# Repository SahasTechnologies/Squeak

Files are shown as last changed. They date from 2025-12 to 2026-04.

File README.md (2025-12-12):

## Squeak Mouse

Here is my custom designed mouse! It's my first time on Onshape, so I don't know how well this will turn out but a good chance to learn about how to use onshape. The finished product is [here](https://github.com/SahasTechnologies/Squeak/blob/main/Squeak%20All%20Parts%20(DO%20NOT%20PRINT).step) and the image is below:

+¬¦˜+¦+¦¦+¦s

The other 3 files can be printed to put together to get an assembled mouse!

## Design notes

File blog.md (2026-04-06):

<!--
  This journal is auto generated by Hack Club Blueprint.
-->

# 12/13/2025 8 AM - Squeak  

_Time spent: 0.5h_  

I am following this guide:


It says no journal required so I won't journal on the mouse CAD design and development. I'll just journal the finished mouse  

# 12/13/2025 9 AM - Finished!  

_Time spent: 4.0h_  

My CAD: [Squeak](https://cad.onshape.com/documents/1791d452b1ce2d56df0d7c44/w/8ed75c21a1f838e67c8c7ae7/e/896395b3e92be339e637faea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)

\

I'll ask someone in Printing Legion to print it, here are the 3MF Files

[+¬¦˜+¦+¦¦+¦s](/user-attachments/blobs/proxy/eyJfcmFpbHMiOnsiZGF0YSI6MjMyMTAsInB1ciI6ImJsb2JfaWQifX0=--c7a4f6c06d3aa04bb595d4f705606054159b0e09/%2B%C2%AC%C2%A6%CB%9C%2B%C2%A6%2B%C2%A6%C2%A6%2B%C2%A6s.3mf)
[+¬¦˜+¦+¦¦+¦s - battery tab](/user-attachments/blobs/proxy/eyJfcmFpbHMiOnsiZGF0YSI6MjMyMTEsInB1ciI6ImJsb2JfaWQifX0=--efa1e4063500dd317ee7b0db9eb5cb296b28a180/%2B%C2%AC%C2%A6%CB%9C%2B%C2%A6%2B%C2%A6%C2%A6%2B%C2%A6s%20-%20battery%20tab.3mf)
[+¬¦˜+¦+¦¦+¦s - base](/user-attachments/blobs/proxy/eyJfcmFpbHMiOnsiZGF0YSI6MjMyMTIsInB1ciI6ImJsb2JfaWQifX0=--f1f21aa12148745eb043641fe057322c68a11a4b/%2B%C2%AC%C2%A6%CB%9C%2B%C2%A6%2B%C2%A6%C2%A6%2B%C2%A6s%20-%20base.3mf)

# 12/14/2025 - BOM  

_Time spent: 1.0h_  

[My BOM](https://github.com/SahasTechnologies/Squeak/blob/main/bom.csv)

| Item | Price in AUD | Price in USD | Shipping (USD) | Total Cost (USD) |
|---|---|---|---|---|
| Bambu Lab Mouse Kit | $16 | ~$11 | ~$6 | $17 |
| 3D prints | $0 | $0 | $12 (max) | $12 |
| | | | | $29



# 1/22/2026 8:19 AM - Components arrived  

_Time spent: 0.5h_  

🎉🎉🎉
Now that the printlegion stuff arrived i can actually stary making. First look though, many of the parts were printed separately instead of together, so super gluing all of this together won't be that easy...



# 1/22/2026 8:24 AM - Assembled all components  

_Time spent: 1.5h_  

mouse
[Video of the mouse working](/user-attachments/blobs/proxy/eyJfcmFpbHMiOnsiZGF0YSI6ODc4MTYsInB1ciI6ImJsb2JfaWQifX0=--4eaad5631bd95a56bf42be9cb9b51019d38cb931/20260121_195300.mp4)

# 1/22/2026 8:28 AM - Noooooooo  

_Time spent: 0.5h_  

So, as i was saying earlier in need to superglue the parts on, and when I tried to  assemble of the 3d parts... it just broke 🙁

It's not that bad since im going to super glue it anyway and even if i dont it doesnt cause any harm to my actual project, but either way it's sad that I already broke a part



Before assembling though I had spent some time putting the parts together because there are many small parts that should have been printed eith the actual case (e.g the protrusions on the inside of the mouse case that actually click the button)

Here is how the mouse should look like when im done


# 1/25/2026 3:11 PM - Superglued first part on  

_Time spent: 2.5h_  

This took a bit of time to setup and do. Before I start, it's important to understand that in my CAD design, this was all one file, but the slicer had made them two separate objects entirely. Therefore, there is no clearance space to wedge the parts in together sadly.

I spent a lot of time trying to get the parts to actually fit in 😶



So, after trying a lot to wedge, I had to resort to cutting a bit of filament off (and hoping the screw hole still works for later).


So, now after a long time it finally decided to fit on, which is a relief. But, it didnt fit perfectly and kept springing back no matter how hard i tried

So i had to superglue these parts to each other so that they can actually fit  

# 1/25/2026 3:19 PM - Assembled rest of the mouse  

_Time spent: 1.0h_  



The mouse is fully assembled now and it is working so yeah, here is a video of jt working[20260125_151815](/user-attachments/blobs/proxy/eyJfcmFpbHMiOnsiZGF0YSI6OTA2MTYsInB1ciI6ImJsb2JfaWQifX0=--8417cb071001bc2bd6b273fe5f60a4531131c02e/20260125_151815.mp4)

# 1/26/2026 - Social media  

_Time spent: 1.0h_  

social media is sadly banned in australia for under 16s
also jay said i can uplaod to cdn 
[see here](https://hackclub.slack.com/archives/C09CMJV6V6K/p1766012356714549?thread_ts=1766006526.978849&cid=C09CMJV6V6K)
anyway so yeah here is my mouse



if you specifically need it in #cdn then here is the video in cdn
oh wait cdn doesnt work thats sad
here is the link to the file on slack at least
https://hackclub.enterprise.slack.com/files/U09QBEKG4S0/F0AAZ6FHDNG/20260125_151815.mp4

I got this error for #cdn:
https://hackclub.slack.com/archives/C016DEDUL87/p1769384952272139?thread_ts=1769384947.905419&cid=C016DEDUL87
thanks, i'm gonna sell these to adfly![10:49 AM]orpheus trips and your files slip out of her hands and into an inconveniently placed sewer grate.[10:49 AM]Something went wrong: RuntimeError: cdn returned error 500: {"error":"Internal server error"}      
// stack trace:
/app/app/interactions/cdn.rb:29:in `upload_to_cdn'
/app/app/interactions/cdn.rb:47:in `block in call'
// nora, please go find the full trace
// code available at https://github.com/hackclub/orpheus-bot
error ID: 34df5310-1e1d-4d2a-8b78-ae203bc0a99f  

# 07/4/2026 - Improvements for next time

_Time spent: 0.1h_  

This is very sad...
I got the mouse to 'work', but while supergluing everything, some liquid fell inside the right button :(
tempFileForShare_20260407-073727

So now, the left click works perfectly, but the right click does not. I think there were two errors that played during this:

### 1. The print was not printed properly
During the printing process, what happened was that each one of my parts on onshape were split into 5 other parts... without this I wouldn't have had to superglue anything on. With these parts, the buttons that actually pressed on the mouse were sepertae from the body for some reason, which meant I hadto precision assemble myself, and more parts means more things can go wrong. I think next time I should be more incolved in my printing process, and even though my CAD files are technically al lin onepiece, I should confirm with the printer before printing this

### 2. I wasn't careful with the superglue
Well, with this, I thought that sticking the actual small part that will press the button to the top of the mouse will be hard, so I stuck it on the key itself. For the left key it worked fine, but the right key managed to get superglued :(. Because of this, I can't use the right key. I think next time I should be more careful with the superglue, or since I can't handle superglue I should make sure the prints arrive in a way that I don't have to superglue stuff together and cut stuff of prints like I am doing now.

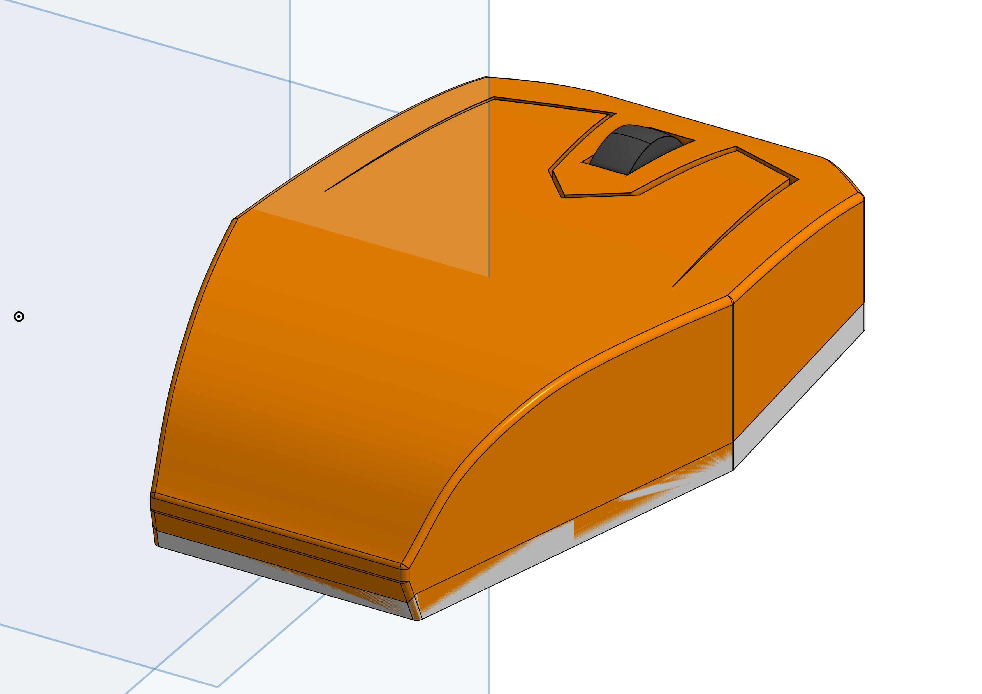
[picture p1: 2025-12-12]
+¬¦˜+¦+¦¦+¦s.png

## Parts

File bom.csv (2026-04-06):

Item | Price in AUD | Price in USD | Shipping (USD) | Total Cost (USD)
Bambu Lab Mouse Kit | $20 | ~$14 | ~$6 | $20
3D prints | $0 | $0 | $12 (max) | $12
 |  |  |  | $32

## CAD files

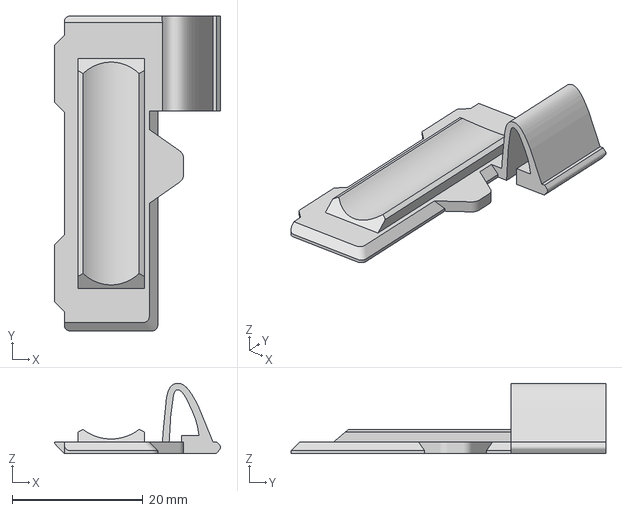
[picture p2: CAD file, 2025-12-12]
Squeak - battery tab.3mf
25.4 x 48.2 x 10.8 mm

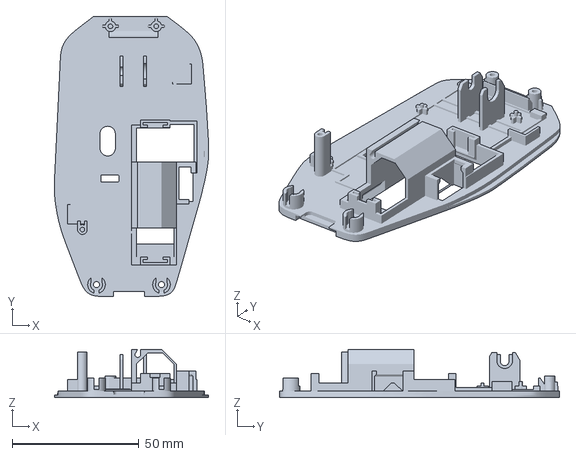
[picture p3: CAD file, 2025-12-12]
Squeak - base.3mf
61.1 x 110.7 x 19.1 mm

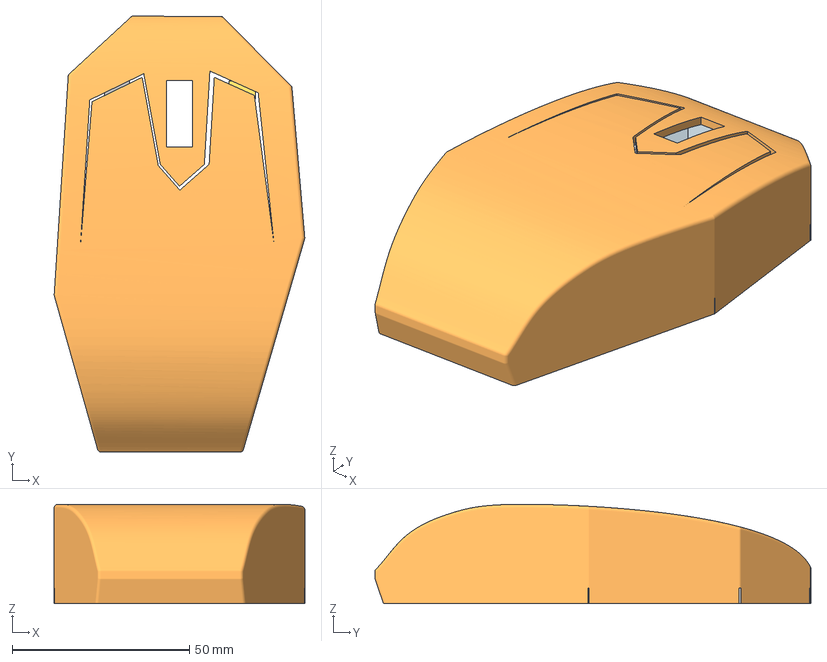
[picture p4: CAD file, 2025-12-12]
Squeak.3mf
70.7 x 123.0 x 28.1 mm

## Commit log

2025-12-12 Update README with assembly instructions for mouse
    Added information about assembling the mouse using other files.
2025-12-13 Remove extra columns from bom.csv
    [bom.csv]
2026-04-06 Update prices in bom.csv
    Updated the price and total cost for Bambu Lab Mouse Kit and adjusted the total cost for the last item.
    [bom.csv]
